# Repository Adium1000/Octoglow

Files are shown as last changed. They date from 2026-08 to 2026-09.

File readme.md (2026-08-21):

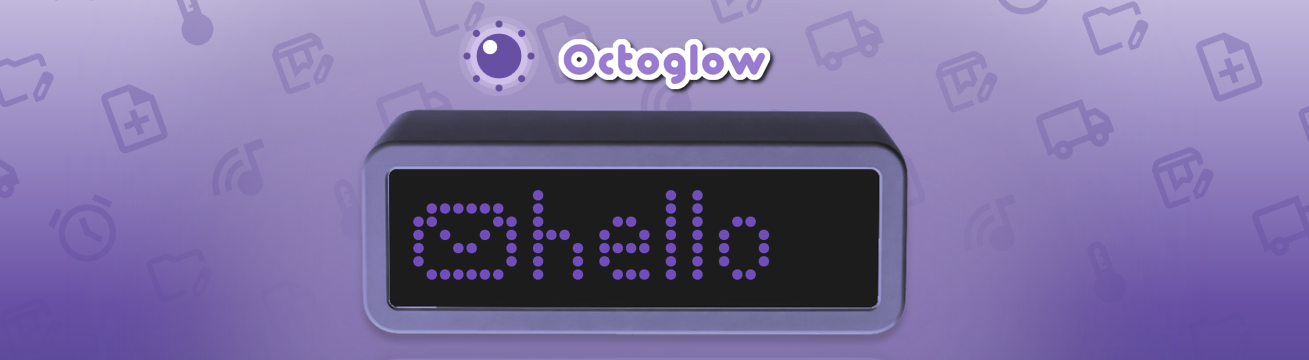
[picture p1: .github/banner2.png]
banner


A compact smart desk clock firmware that connects to Wi-Fi, syncs time automatically, and displays time, date, temperature, and atmospheric pressure  all in one firmware.

## Table of Contents

- [Features](#features)
- [DIY](#diy)
- [Bill of Materials (BOM)](#bill-of-materials-bom)
- [Octoglow Sender](#octoglow-sender)
- [Find my Octoglow's IP adress](#how-can-i-find-my-octoglows-ip-adress)

## Features
Octoglow displays information in "tiles" that rotate one after another, each with its own display duration, all configurable from the dashboard (you can enable/disable each tile and reorder them via drag & drop), Here is a list with all tiles:

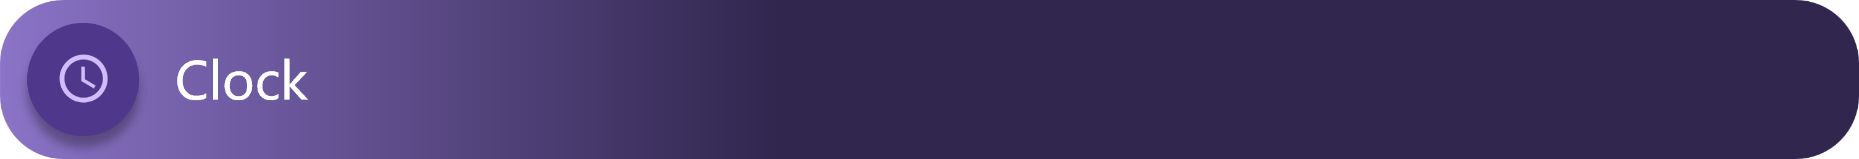
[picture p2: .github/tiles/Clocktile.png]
#clock


This tile shows the current time, synced automatically once the clock connects to the internet, so you never have to set it by hand.

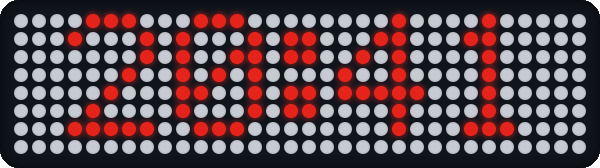
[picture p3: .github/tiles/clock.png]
Clocktile


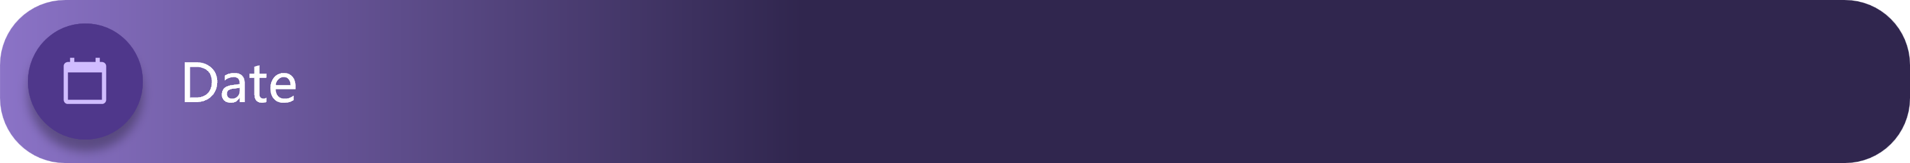
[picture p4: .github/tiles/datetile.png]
datatile


This tile shows the current date, pulled from the same internet time sync as the clock, so it always stays accurate.

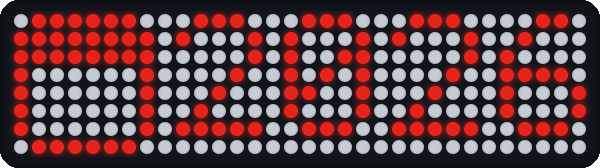
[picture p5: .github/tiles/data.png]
Datatile


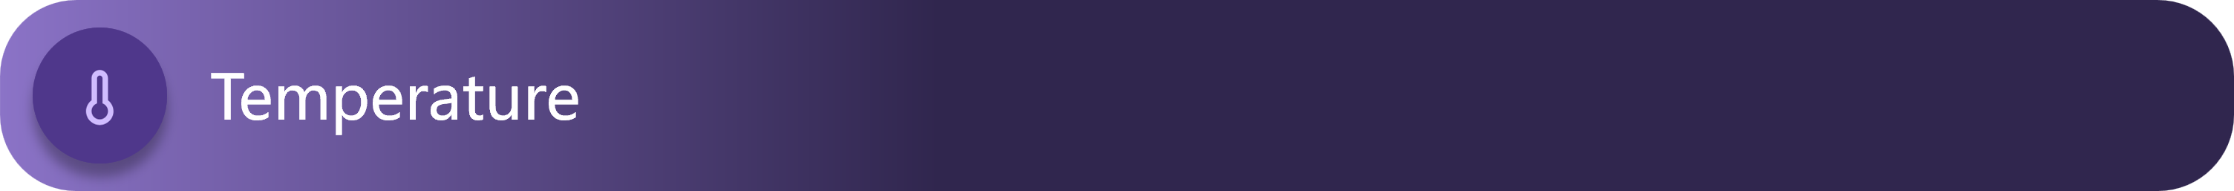
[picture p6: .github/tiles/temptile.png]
temptile


This tile shows the ambient temperature at your clock's location, as long as you have a temperature sensor connected to the i2c rails.

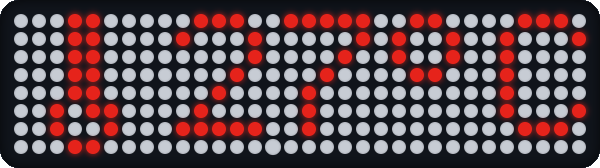
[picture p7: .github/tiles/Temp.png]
Temptile


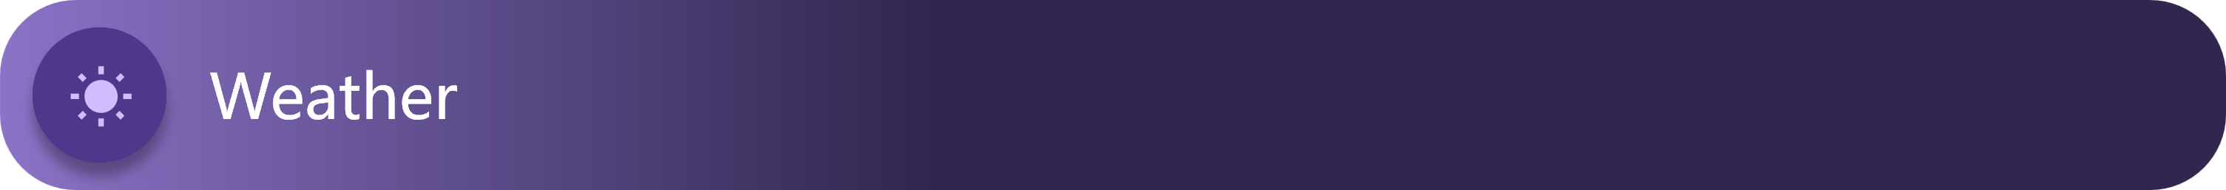
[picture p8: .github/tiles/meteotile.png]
meteotile


This tile fetches live weather data for your set location once you add an OpenWeatherMap API key. It scrolls through the current temperature (in Celsius or Fahrenheit, your choice), humidity percentage, and a short text description of the conditions, along with a matching weather icon.

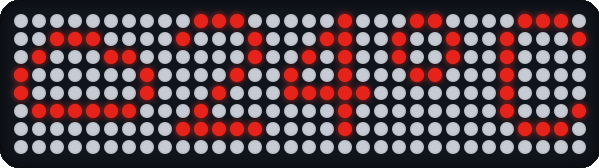
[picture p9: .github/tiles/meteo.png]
WeatherTile


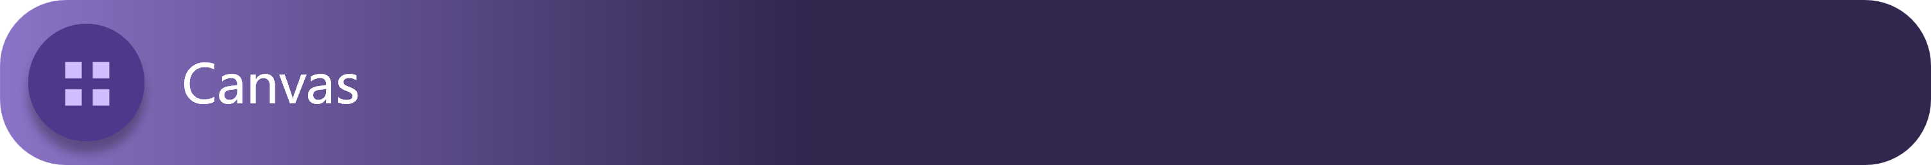
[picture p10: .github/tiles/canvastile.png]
canvastile


This tile turns the whole 8x32 LED matrix into a drawing surface, letting you sketch or design your own custom pixel art directly on the display.

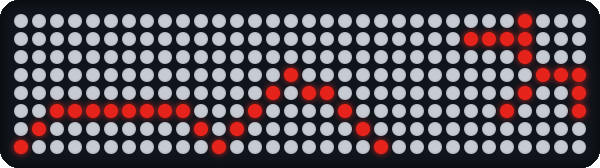
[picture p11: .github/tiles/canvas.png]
CanvasTile


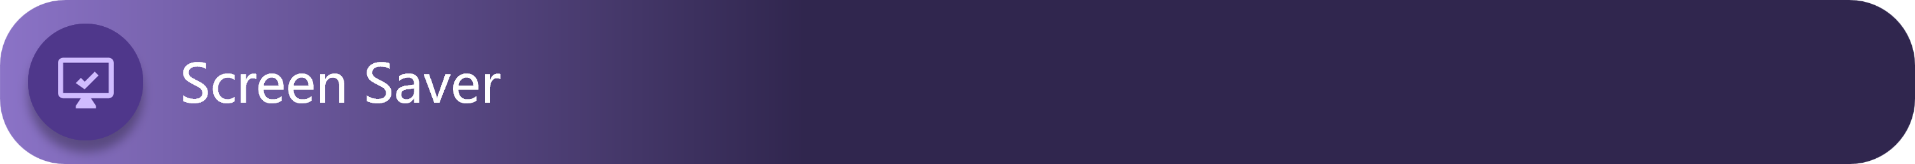
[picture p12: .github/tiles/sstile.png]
sstile


This tile plays one of three animations when idle: a self-playing Pong match between two paddles, a fireworks show with launching rockets and bursting particles, or an audio equalizer style animation with bouncing bars. You can pick a specific one or let it choose randomly each time.

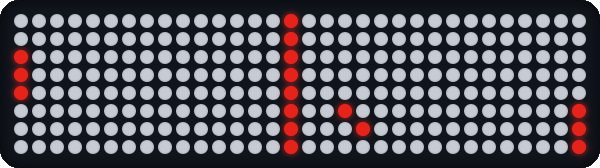
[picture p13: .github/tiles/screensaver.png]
screenssavertile


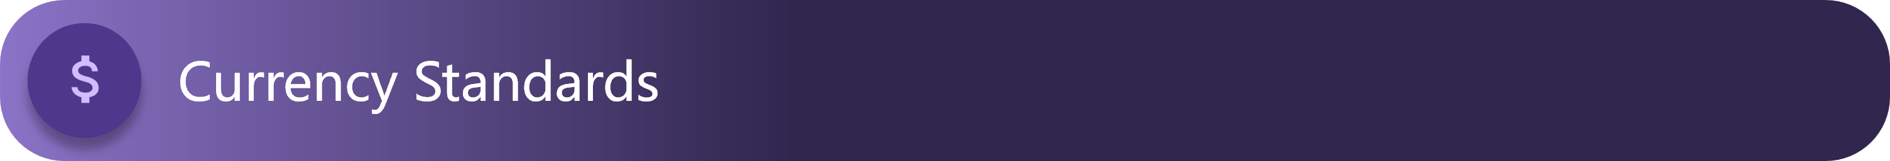
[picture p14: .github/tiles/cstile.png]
cstile


This tile shows the exchange rate for a currency you select, and optionally compares it against a second currency. It also displays a trend arrow showing whether the rate has gone up, down, or stayed flat compared to a month ago.

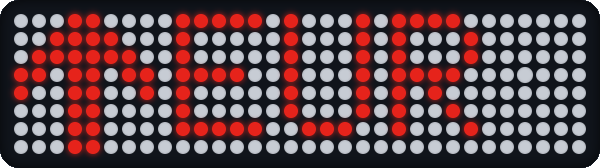
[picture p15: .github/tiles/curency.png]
curencytile


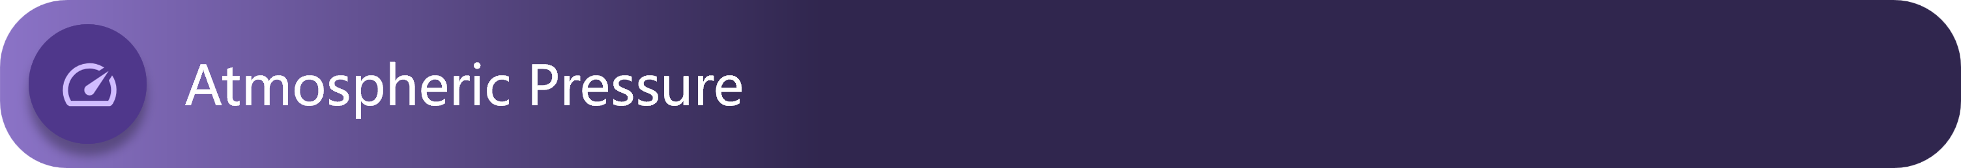
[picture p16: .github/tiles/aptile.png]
aptile


This tile shows the current atmospheric pressure in hPa, as long as your clock has a barometric pressure sensor connected to the i2c rails. It also shows a trend arrow based on how the pressure has changed over recent readings.

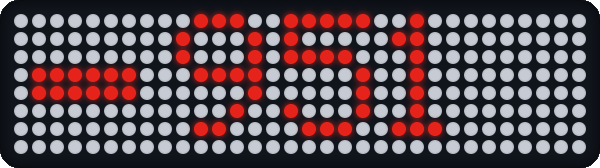
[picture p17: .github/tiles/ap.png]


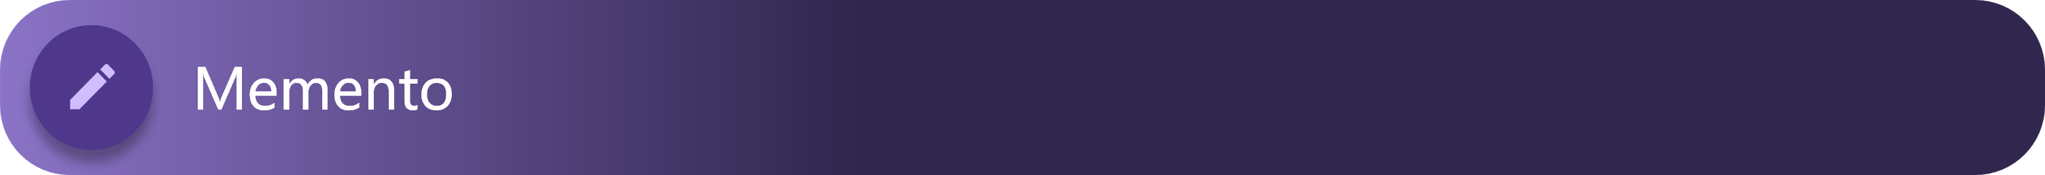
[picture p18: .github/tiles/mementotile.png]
Memento


This tile lets you create short personal notes or reminders that scroll across the display.

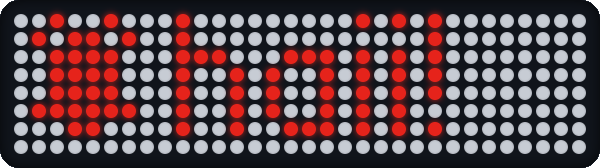
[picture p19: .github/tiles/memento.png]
Memento?Nahbro


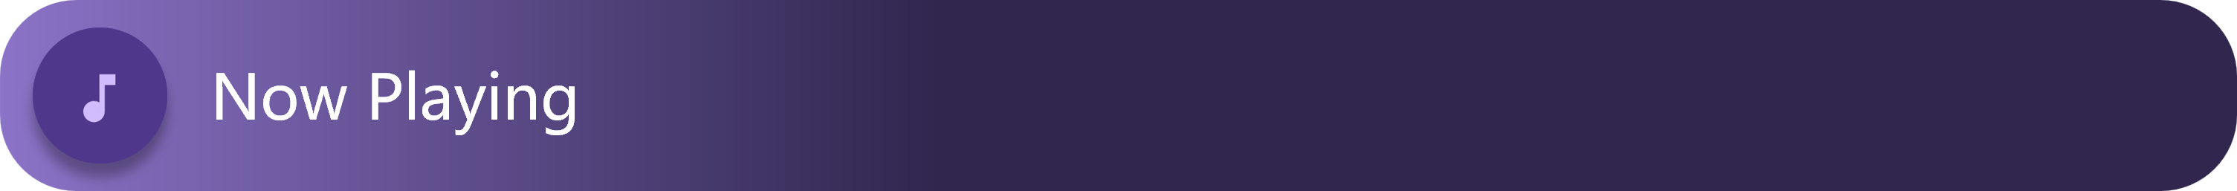
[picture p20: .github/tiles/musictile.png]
musictile


This tile displays the artist and track title of whatever you're currently listening to on your device, sent live from the companion Watch Sender app.

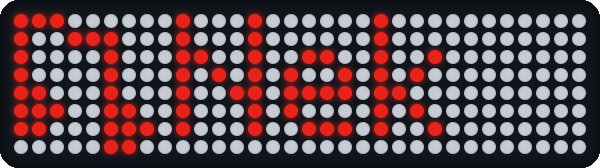
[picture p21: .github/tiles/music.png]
HmmNowPlayingGuta?


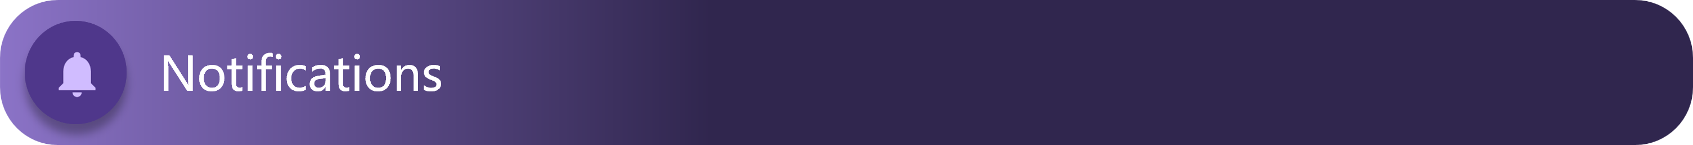
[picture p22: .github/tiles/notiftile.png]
notiftile


This tile shows notifications received on your computer as they come in, forwarded through the Watch Sender app and scrolled across the display.

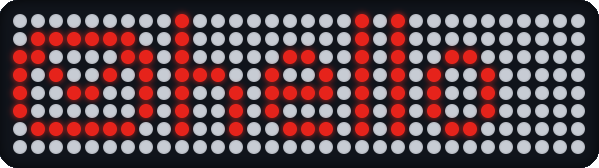
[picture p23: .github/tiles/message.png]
Ugotmailtile


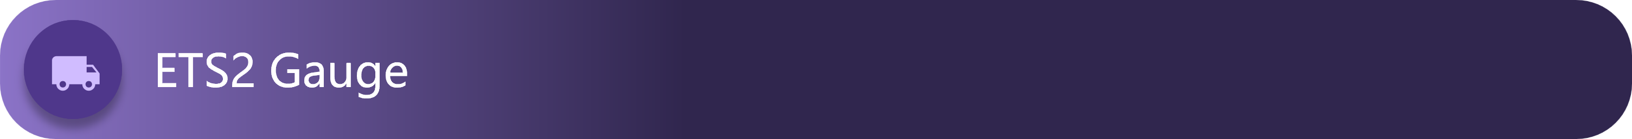
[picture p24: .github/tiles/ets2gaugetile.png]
ets2


This tile shows your real-time speed in km/h while driving in Euro Truck Simulator 2, streamed live from the game through the Watch Sender app.

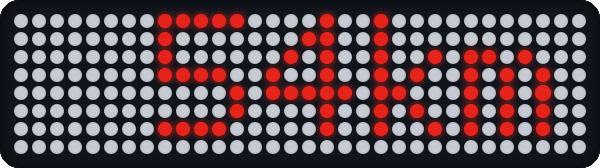
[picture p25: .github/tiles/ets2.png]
Ets2tile


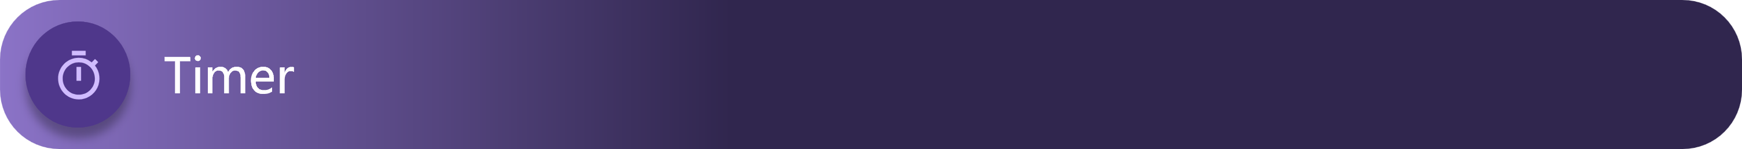
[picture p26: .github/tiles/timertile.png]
timertile


This tile runs a countdown timer that you can set to a custom duration or pick from preset values, showing the remaining time and alerting you with a sound once it hits zero.

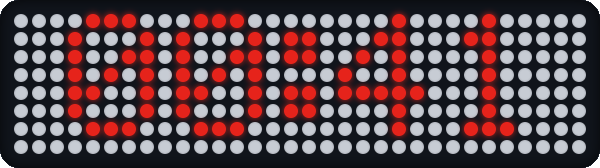
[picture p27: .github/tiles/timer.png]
tikitikitikitile


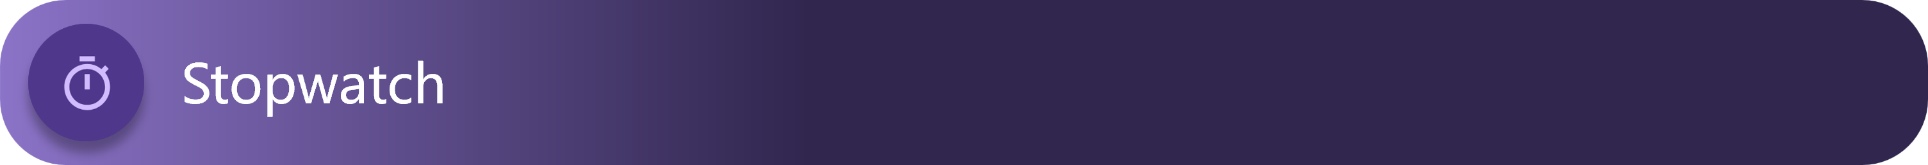
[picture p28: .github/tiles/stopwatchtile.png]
stopwatchtile


This tile lets you time things using your clock, with start, pause, and reset controls right from the interface.

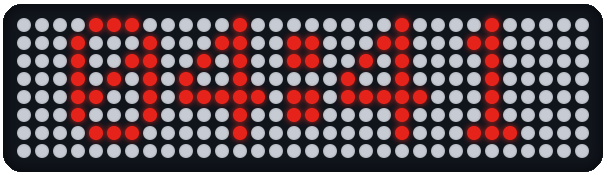
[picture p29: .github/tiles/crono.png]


## Configurations and Settings

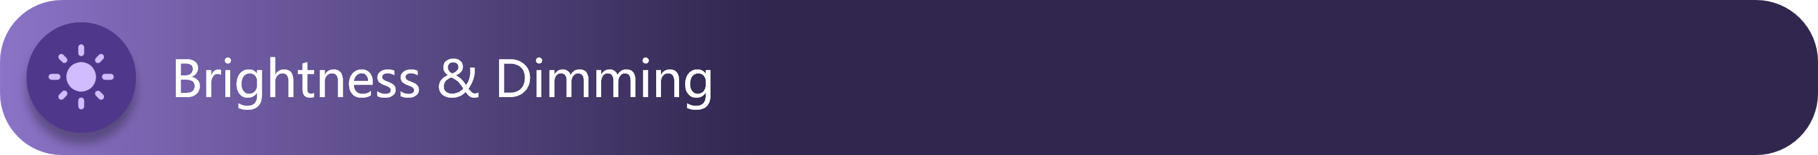
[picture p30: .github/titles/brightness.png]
Brightness & Dimming


- 17 brightness levels (0 = display fully off, 1-16 = actual intensity on the MAX7219 matrix).
- **Scheduled auto-dimming**: set a time window (e.g. 10 PM - 7 AM) during which the display automatically switches to a lower brightness, so it doesn't blind you at night.

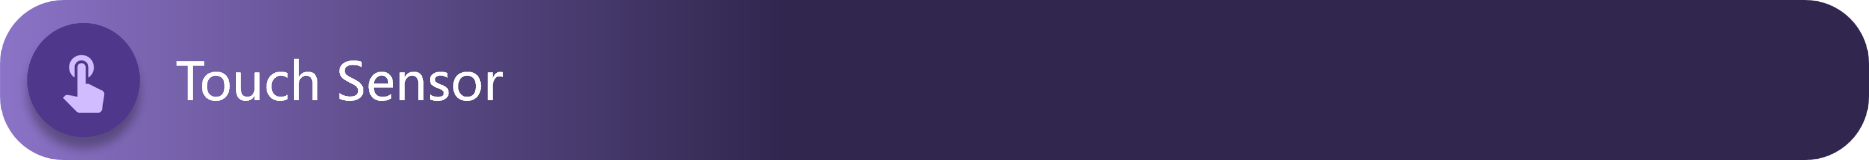
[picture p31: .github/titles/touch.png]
Touch Sensor


A TTP223 capacitive sensor enables physical interaction with the clock, with separately configurable actions for **tap** and **double tap**:

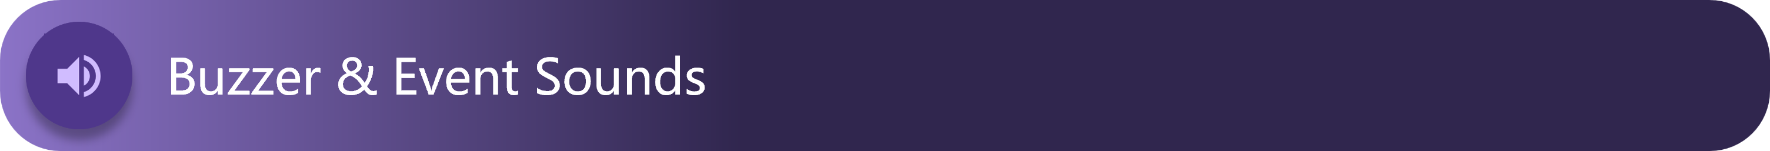
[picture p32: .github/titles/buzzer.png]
Buzzer & Event Sounds


- Buzzer on/off 
- Sound presets: Calm, Loud, Urgent, Soft, Double Beep, Triple Beep.
- Separately configurable sounds for each event type: tile switching, Wi-Fi disconnection, new notification, ETS2 speeding, touch sensor tap  with a wider tone library available here too (Chime, Bell, Doorbell, Xylophone, Harp, Marimba, etc.).

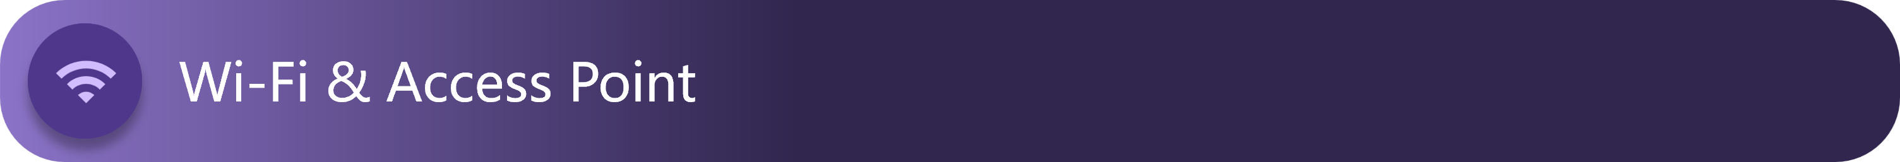
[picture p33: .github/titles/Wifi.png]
Wi-Fi & Access Point


- Connects to your Wi-Fi network (STA mode) via in-browser provisioning: network scan, password entry.
- If no Wi-Fi is configured (or if you choose to switch manually), it starts its own **AP hotspot** (defaults to "Octoglow"), with a configurable SSID and password, for direct access to the dashboard.
- You can switch between AP mode and Wi-Fi mode from the dashboard at any time.

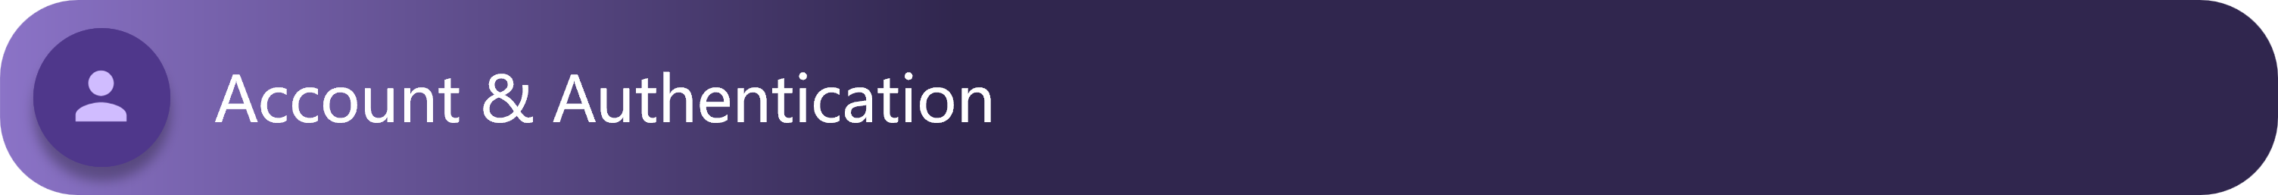
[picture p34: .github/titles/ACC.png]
Account & Authentication


The dashboard is protected with a username + password (cookie-based session). You can change your username and password anytime from the account section.

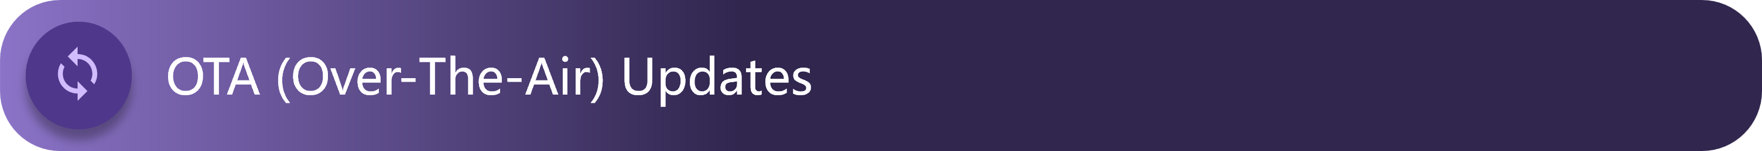
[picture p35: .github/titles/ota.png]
OTA (Over-The-Air) Updates


The firmware can check its own version against the GitHub repo and update itself wirelessly, straight from the dashboard:

1. The clock reads the published version from the repo and compares it against the installed version (`FW_VERSION`).
2. If a newer version is available, the dashboard shows the changelog and an install button.
3. The update (`.bin`) is downloaded and flashed onto the ESP32 via the `Update` library, followed by an automatic restart.

## DIY

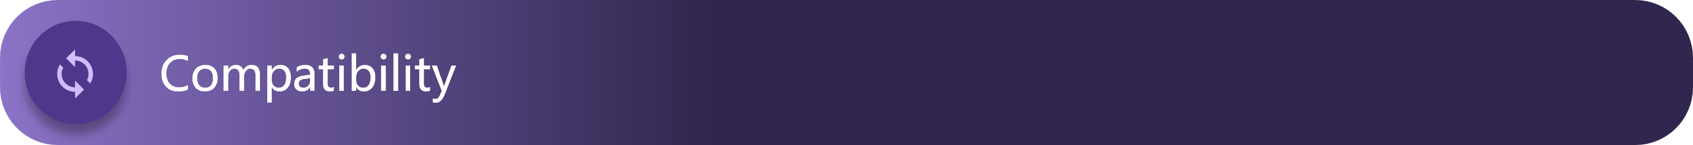
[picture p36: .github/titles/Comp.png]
Compatibility


The firmware should work on any ESP board, although it was tested on the following boards:

- ESP32-S3
- ESP32-C3

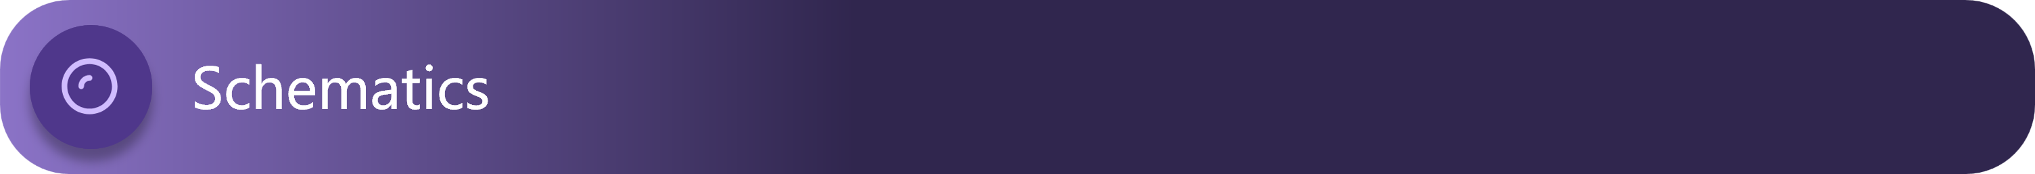
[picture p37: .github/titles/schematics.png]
Schematics


Here is a full schematic you can build if you want your Octoglow to run on battery
(the battery circuit is optional and can be skipped).

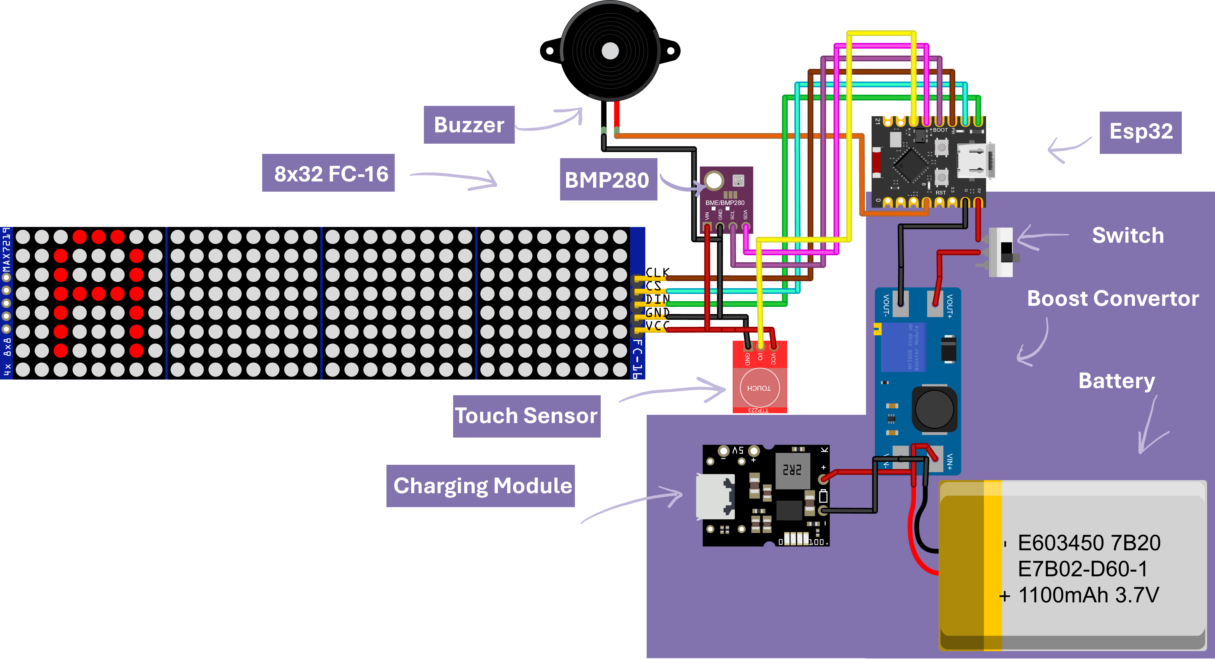
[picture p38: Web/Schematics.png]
schematics


| Component | GPIO |
|---|---|
| MAX7219 DIN | GPIO1 |
| MAX7219 CLK | GPIO3 |
| MAX7219 CS | GPIO2 |
| BMP280 SDA | GPIO5 |
| BMP280 SCL | GPIO4 ||
| Touch I/O | GPIO6 |
|Buzzer| GPIO7|
---

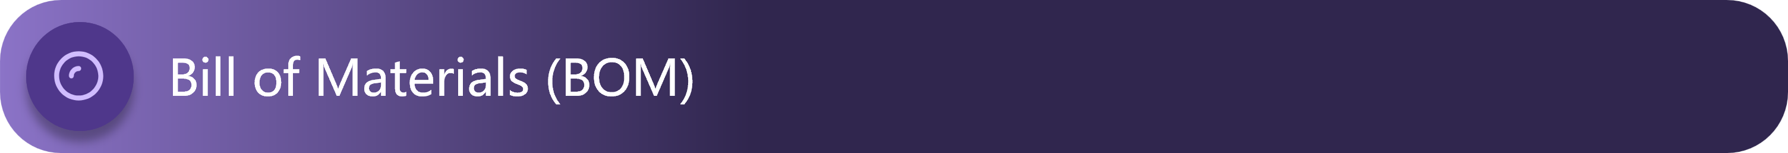
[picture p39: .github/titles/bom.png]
Bill of Materials (BOM)


| Item | Description | Qty | Unit Price ($) | Total ($) | URL |
|---|---|:---:|---:|---:|-----|
| LED Matrix 4x MAX7219 | 4-in-1 chained MAX7219 red LED matrix module | 1 | $6.98 | $6.98 | [Link](https://sigmanortec.ro/en/led-matrix-module-4x-max7219-red) |
| ESP32-C3 SuperMini | WiFi/BT microcontroller board 3.3V | 1 | $6.09 | $6.09 | [Link](https://sigmanortec.ro/en/esp32-c3-supermini-development-board-33v-wifi-bluetooth) |
| TTP223 Touch Sensor | Capacitive touch button module | 1 | $0.69 | $0.69 | [Link](https://sigmanortec.ro/en/capacitive-button-ttp223-touch) |
| TP4056 + Boost 5-24V | Battery charger with boost converter 5-24V | 1 | $1.75 | $1.75 | [Link](https://sigmanortec.ro/modul-incarcare-baterie-cu-ridicator-5-24v-tp4056) |
| IP2312 Charger USB-C 3A | Li-Ion charger 5V→4.2V CC/CV Type-C 3A QC | 1 | $2.75 | $2.75 | [Link](https://sigmanortec.ro/modul-incarcare-litiu-5v-la-42v-ip2312-cv-cc-type-c-3a-qc) |
| Mini Switch | Small slide switch, 2 positions | 1 | $0.22 | $0.22 | [Link](https://sigmanortec.ro/en/mini-switch-2-positions) |
| 18650 2500mAh x2 | Samsung 25R 18650 3.7V 2500mAh - set of 2 | 1 | $15.55 | $15.55 | [Link](https://sigmanortec.ro/set-2-acumulator-li-ion-25r-18650-37v-2500mah-8c) |
| BMP280 Sensor 5V | Pressure and temperature sensor 5V | 1 | $2.03 | $2.03 | [Link](https://sigmanortec.ro/en/pressure-and-temperature-sensor-bmp280-5v) |
| 3D Printing | Custom 3D printed case (Printing Legion) | 1 | $12.00 | $12.00 | - |
| **TOTAL** | | | | **$48.06** | |

---

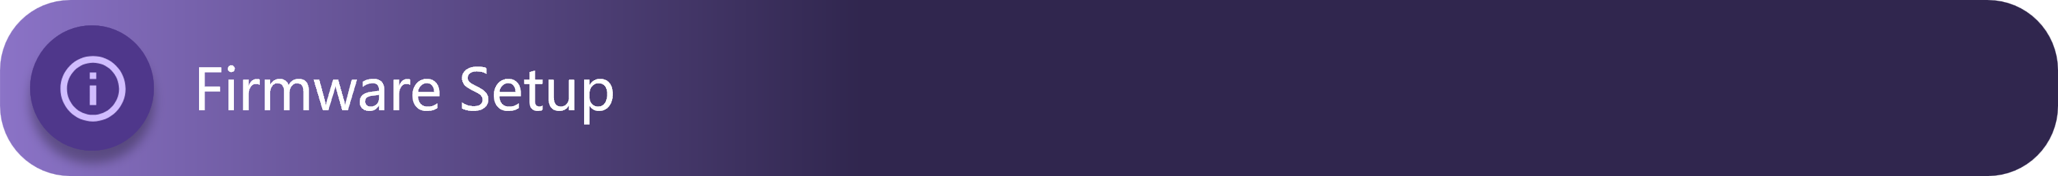
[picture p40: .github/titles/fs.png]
Firmware Setup


1. Open `Octoglow.ino` in the Arduino IDE (You can get it form `/Firmware/`)
2. Install the ESP32 board package from Boards Manager, if you don't have it yet.
3. Install the required libraries from the Library Manager:
   - `MD_Parola`
   - `MD_MAX72xx`
   - `Adafruit_BMP280`
   - `ArduinoJson`
   - (`WiFi`, `SPI`, `Wire`, `WebServer`, `Preferences`, `HTTPClient`, `Update`, `StreamString`, and `mbedtls` are already bundled with the ESP32 core)
4. Select your board and the correct serial port.
5. Upload the firmware.
6. On first boot, the clock starts in **AP mode**  connect to its Wi-Fi network and open `192.168.4.1` in your browser to set up its connection to your home network.

## Octoglow Connect

Octoglow Connect is a app that makes your matchine comunicate with your octoglow device by sending data over the internet to your octoglow device

Octoglow_Connect

What it does?

- **Now Playing**  detects the song currently playing on your Matchine (Spotify, browser, etc.) via the Windows Media Session and sends it every few seconds.
- **Windows Notifications**  listens for toast notifications on Windows and forwards them to the clock (with automatic diacritics removal and truncation to a maximum character count).
- **Euro Truck Simulator 2**  if the game is running, reads live telemetry (current speed) and streams it to the clock in real time. Requires an extra one-time plugin install in-game  see Setting Up ETS2 Speed Integration.

Setting Up

First, you will need to get you Octoglow's IP adress and insert it in the `IP Adress` text box (you can ignore the port most of the times) in the conection tab

### How can I find my Octoglow's IP adress?

## By router's dashboard

- You can find your Octoglow's IP adress in your router's dashboard 
 - Go to `192.168.0.1` or `192.168.1.1` depending on your router 
   - Login to your router's dashboard (the credentials are ushually writen on the back of your router or you can try User : user and Password:admin )
      - Once logged in look for a category named Clients or Devices or Conections or Whatever it really depends on your router
         - Once u find that category you should see a list of devices, each with an IP adress, and you should see a device named esp... that may be octoglow, copy the IPV4 adress and paste it in the adress bar, if you see the octoglow login screen , you are on the octoglow's dashboard

! Warning : Your octoglow IP adress may change after a while, your IP adress will change so you need to reserve IP address

## By tapping the touch sensor on your Octoglow 

- If you did not unasign the "show IP adress" in the touch sensor options it should show your IP , but your IP adress will change so you need to reserve IP address

Setting Up ETS2 Speed Integration

The ETS2 tile shows your truck's current speed on the clock, but it needs one extra piece set up in-game before it works: ETS2 doesn't expose any telemetry data on its own  a small plugin has to be installed first.

### Install the SCS SDK plugin (in-game)

1. Download the latest **scs-sdk-plugin** (by RenCloud) from:
   `https://github.com/RenCloud/scs-sdk-plugin/releases`
    grab the Windows archive (`win_x64`).
2. Open your ETS2 install folder. By default it's:
   ```
   C:\Program Files (x86)\Steam\steamapps\common\Euro Truck Simulator 2\bin\win_x64\plugins
   ```
   Create the `plugins` folder if it doesn't exist yet.
3. Copy the `.dll` from the downloaded archive into that `plugins` folder.
4. Launch ETS2. On first launch you may see a confirmation message that the SDK was enabled  click OK.

> If you don't see the confirmation message, make sure the DLL sits directly in `bin\win_x64\plugins\`, not in a subfolder.

## Photos of Octoglow in action

oct1
oct2

Made with 🖤 by Adrian

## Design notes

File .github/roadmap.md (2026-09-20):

# Devlog 1: Fixed the readme

Previously, my readme was written by ai, so it wasn't really that great. It contained a lot of false information about my project, so I decided to remake it, keeping only a few accurate parts from the previous version.
This update adds a lot of images and examples, as well as a banner, making the readme much more pleasant to look at. It took me quite a while to finish, but I'm really satisfied with the final result.

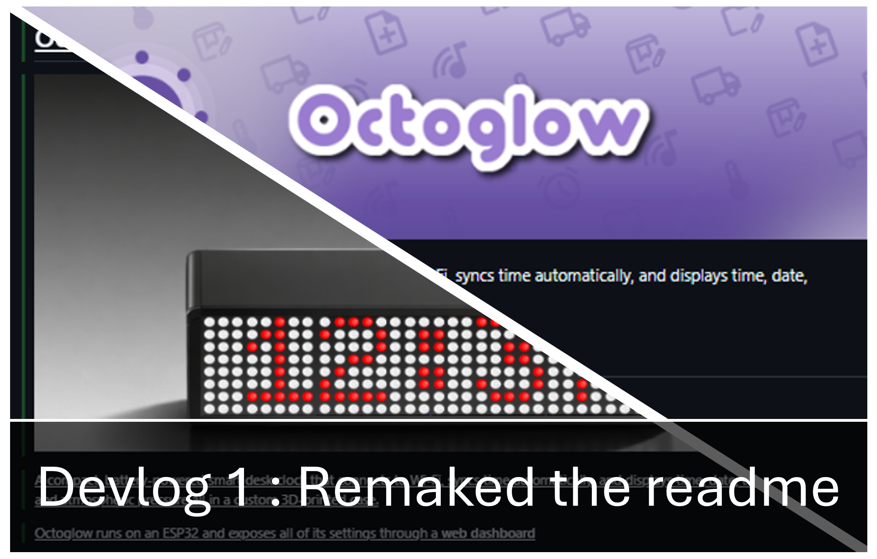
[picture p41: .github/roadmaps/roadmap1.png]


# Devlog 2: UI inconsistency error fixes + WiFi sync bug fix

1. UI inconsistency error fixes
- I tried to identify and fix all of them since in future versions we will be able to set the accent color for the interface
Below are all the fixes for the UI inconsistencies:
 - In Tile Manager: In the "Display Settings" category (My Project is still in Romanian and English, I will do a fix for that later) Tile Transition and Scroll Type used a different category opening arrow than the one on Disable Tile Icons, now they all look the same
 - In the "Switch to AP Mode" popup, the icon on the left and the confirmation button were red, which made the UI a bit inconsistent, now they follow the current accent color
 - In the About category, both Info and Software showed the version info, now it's only in Software, and the order was changed to Info, User, Software
 - In Display, in the "Brightness" category, the brightness icon had a smaller blade than the rest

2. Octoglow WiFi information sync errors

In the past, the firmware had a problem where if /state failed even once (a network blip on the ESP32), the page would permanently fall back to a reduced hardcoded list (without Pressure/Screensaver/Currency) and would stop updating IP/WiFi/version at all, which is why it only worked after a restart, since that redid the fetch
Fix applied: now, if /state fails, the page automatically retries up to 4 times (with increasing delay: 0.5s, 1s, 1.5s, 2s) before falling back to the incomplete fallback. This basically removes the need for a manual restart in unfavorable cases

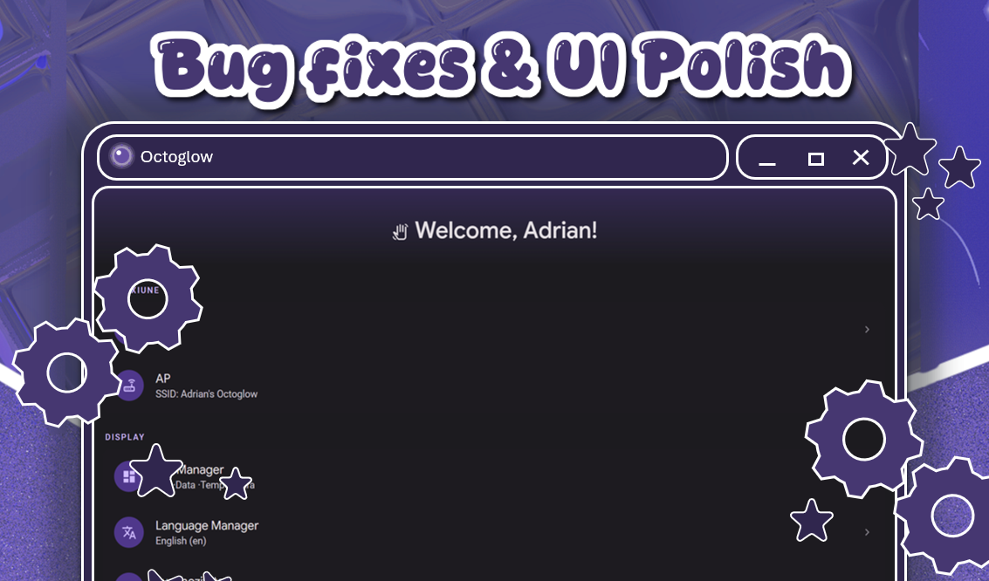
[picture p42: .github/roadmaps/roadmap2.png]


# Devlog 3: Text Engine Fixes

1. Tile Font Inconsistency
Before this fix, the timer, stopwatch, memento, and currency tiles used a different numeric font than the rest of the tiles, something I hadn't noticed until now. As of this update, all tiles now display using the same font.

Before

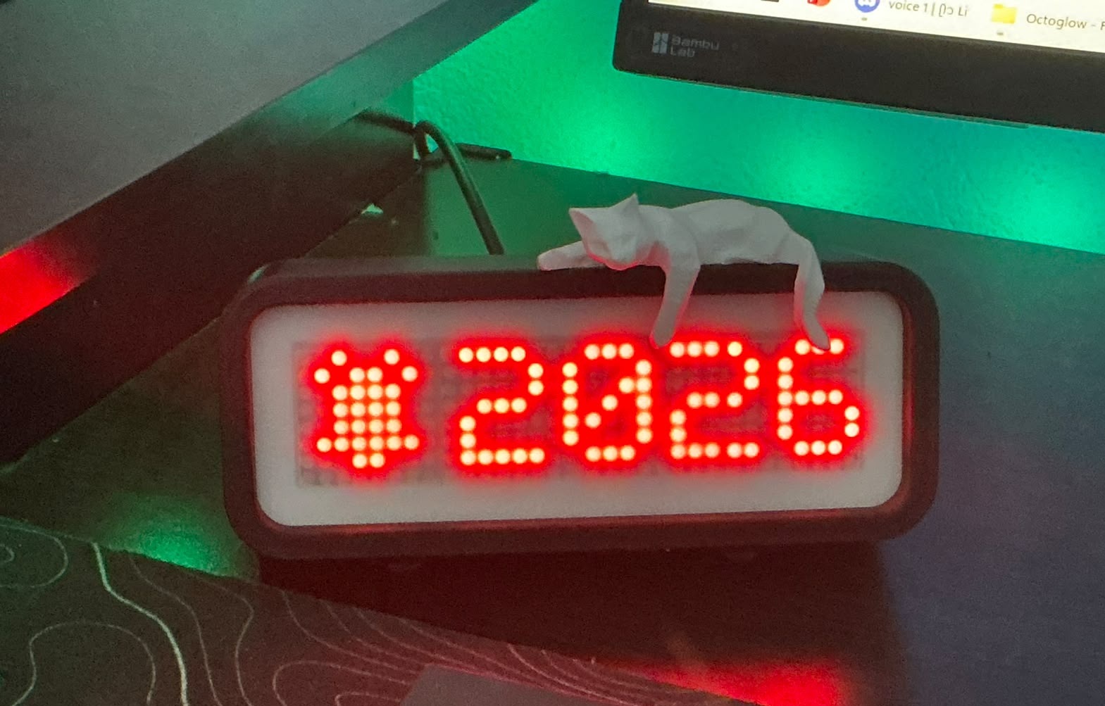
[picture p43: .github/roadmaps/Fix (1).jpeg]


After

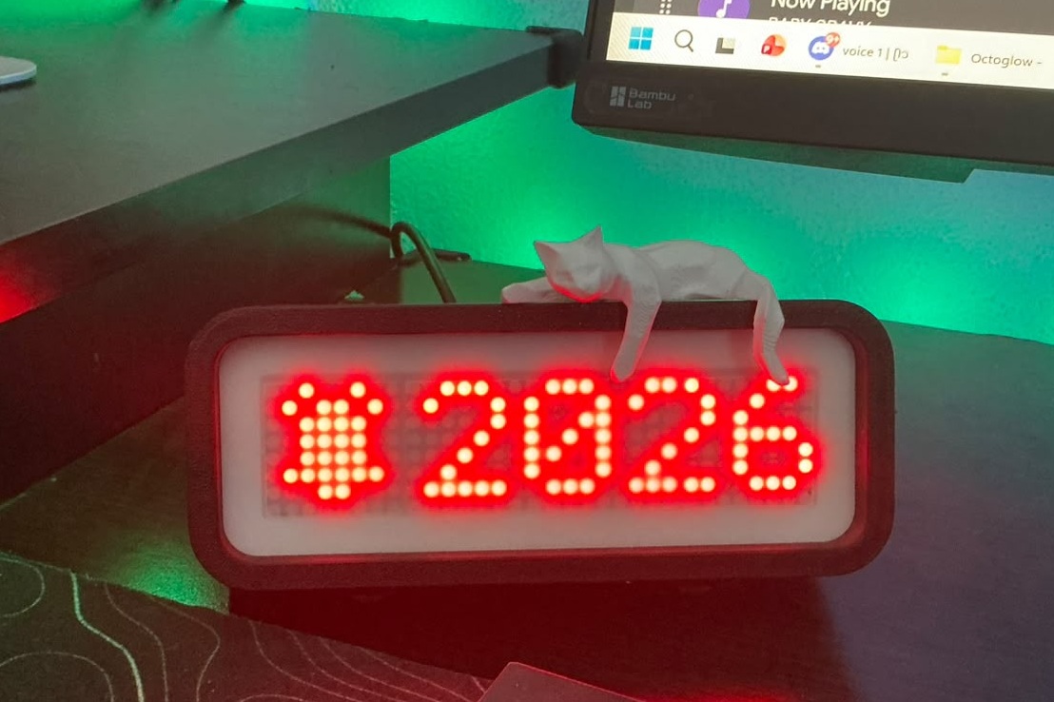
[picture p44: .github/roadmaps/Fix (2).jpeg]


2. Toasts
In previous versions, when logging into the interface, we had no dedicated way to communicate short lived pieces of information, so these messages were scattered around and didn't look good. Starting with this update, the web interface now has the ability to display toasts (a feature I mainly integrated to warn the user that they cannot have 0 active circuit tiles, and that at least one tile of that kind needs to be turned on for the firmware to work correctly. However, I saw an opportunity in this, so I integrated it in other places as well).

Places where we now have toasts:
Failed Login
Successful Wifi Connection
Circuit Tile Exception
AP Mode Switch

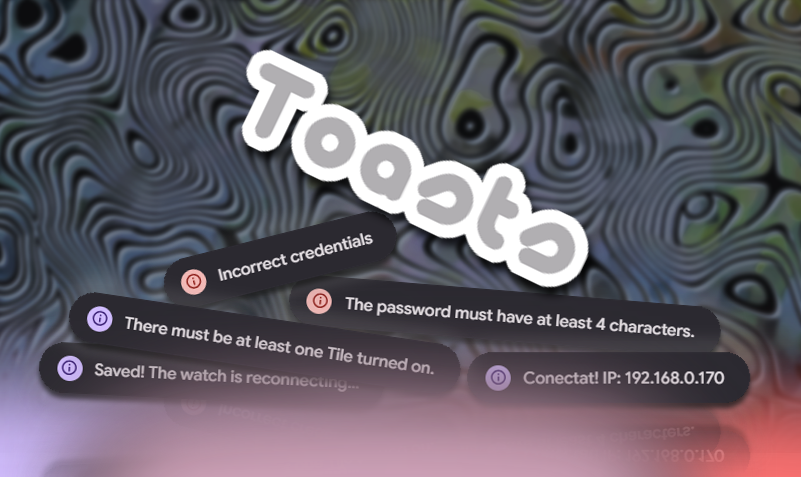
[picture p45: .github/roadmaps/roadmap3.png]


# 4. Fixed tile engine + Easy Discover Utility
### Animation transition fix

Fixed the animation transition on single circuit tiles for a smoother and more consistent visual experience.

### Show IP address through Touch actions

You can now assign `Show IP Address` to `On Touch` or any other supported Touch event from the Touch Options menu.

When triggered, Octoglow will display its current IP address directly on the device. This can be especially useful when using a hotspot for synchronization, or when you want to connect to Octoglow without having to dig through your router settings to find its address.

It makes accessing the interface and setting up synchronization a little easier and more convenient.

## README Updates

### Photos of Octoglow in Action

A new section has been added to the README: **Photos of Octoglow in Action**.

This section is intended as a community gallery where you can share photos of your own Octoglow device. The goal is to build a diverse collection of setups that shows the different ways Octoglow can be used, customized, and built into your own projects.

Whether you went for a clean setup, something completely custom, or found a use case we never thought of, feel free to share it.

And yes, ideally with Octoglow actually being the star of the show. Although I have a feeling some of you might have other plans.

# 5. UAC Redesign + NowPlaying Number Font Fix

## Redesigned the old UAC
Gave the old UAC (login/setup screen) a visual refresh to make it feel more modern and pleasant to use. The layout is now more minimal overall, with less clutter and less text on screen. One of the nicer additions is an automatic guest avatar that generates your initials from the username you type, instead of showing a generic placeholder icon the whole time. Spacing and alignment were also cleaned up so the screen looks tidier on both small and large displays.

## Fixed NowPlaying numeric font
Noticed that the NowPlaying tile was rendering its numbers with a different font than every other tile in the UI, which made it stand out in a bad way. Tracked it down and fixed it so NowPlaying now uses the same numeric font as the rest of the tiles, keeping everything visually consistent.

# 6. Accent Color + 15 New Buzzer tones 

# Accent Color

Now you can change the accent color of the dashboard from the default pink up to any color, (except white and black because they are not colors and they will broke the dashboard) Also there are some prests that I find them looking cool and also an option to custum hex , and restore

And added light mode, if you'd like to use your monitor as a flashlight

# Buzzer Tones

Added a few new buzzer tones, they are pretty basic
Here Is the full list of buzzer tones 

- Calm
- Loud
- Urgent
- Soft
- Double Beep
- Triple Beep
- Chime
- Bell
- Doorbell
- Xylophone
- Harp Glissando
- Marimba
- Crystal Sparkle
- Gentle Wave
- Lullaby
- Ping Pong
- SOS
- Siren
- Klaxon
- Klaxon
- Laser Zap
- Robot Blips
- Fanfare 
- Power Down
- Power Up
- Heartbeat
- Sci-Fi
- Arcade
- Zen Gong
- Bubbles
- Whistle
- Bold Alert

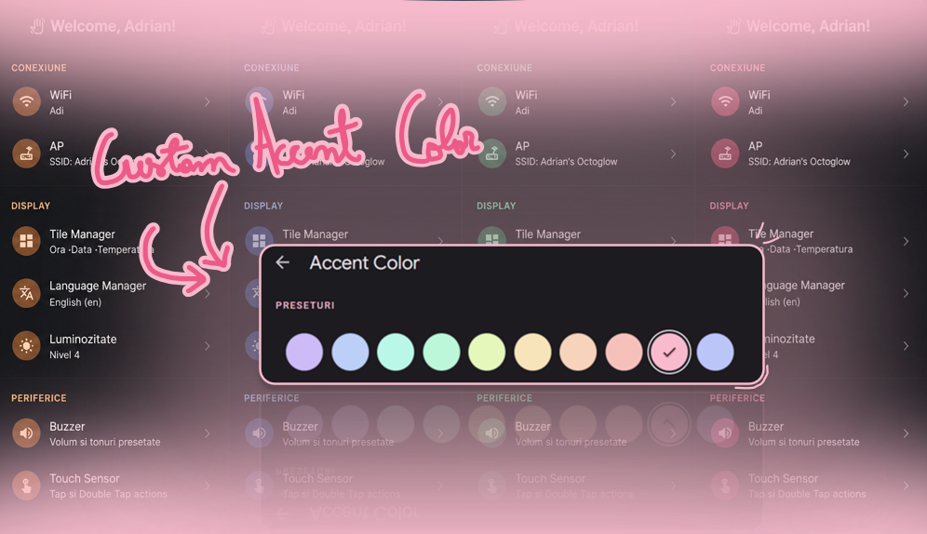
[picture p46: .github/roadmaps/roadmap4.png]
dd


# 7. Released the Octoglow Website + Major Firmware Fixes

## 1. Octoglow Website

Released the new **Octoglow Website**! This page makes the Octoglow setup and introduction easier for new users, while also providing a way to try out the Octoglow dashboard.

## 2. Firmware Updates

* **Fixed Tile Font Issues:** Fixed numeric font issues affecting the following tiles:

  * IP Address
  * Notification

* **Fixed Text Scrolling Freezes:** Fixed most of the freeze issues that occurred when a tile was scrolling text.

* **"Looking for Something Else" Section:** Added a **"Looking for Something Else"** section to the Tile Manager and AP pages. This will help users find information related to these menus.

* **No Re-Login Required:** Fixed the login cache issue. Now, even if you unplug your Octoglow, you can still access it without entering your password again, as long as you have previously logged in or revisited the page within the last 30 days.

* **Connection Issue Popup:** If your ESP loses its internet connection, a popup will now be displayed in the web interface to notify you.

* **Tile Manager Design Improvements:** Improved the design flow in the Tile Manager settings. All custom options for a tile are now displayed in a cleaner list format using radio buttons.

* **Help Manager:** Some tiles now have a **(?)** icon. Pressing it will show information about how to properly configure and use that tile.

* **Custom Date Formatting:** You can now customize the date format however you want using:
  **W, Y, M, D, /, , and .**

Connector App + App Patch

1. Released Octoglow Connect -  A remade version of Octoglow Sender but in C# 

- This app should be more stable, also this app provides more options like:
  - System Default Language Detector
  - System Default Theme Detector
  - Euro Truck Simulator truck Handbrake Detector
  - Now Playing Pause Detector
  - Now Playing Video Player Detecor (Avalabile in the last Python Version of Sender if you compile it by yourself)
  - Backdrop Material 

2. /state bugs fix

In the last patch of thre Octoglow Firmware, I tryed to patch the most reasons why the state command will fail to reach back the server, that may make the web experience smoother and more reliable 

3. Released Demo on the site 

Great news! If you want to test a Demo version of the web interface before flashing you can now try it

4. Fixed Schematics

Before the buzzer was connected on pin 7, now it is indeed conected in the pin 12
Maked the picture text more readable

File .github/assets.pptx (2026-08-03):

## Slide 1

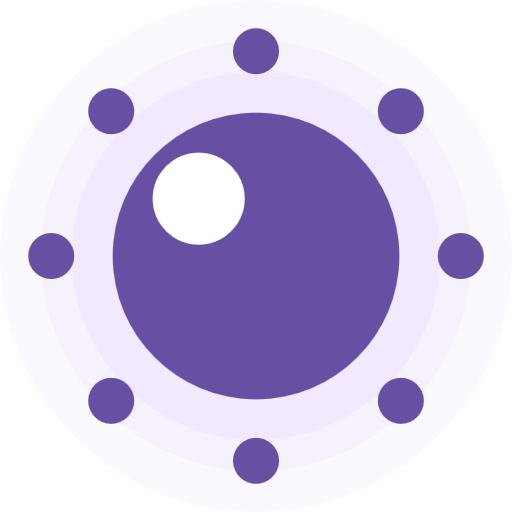
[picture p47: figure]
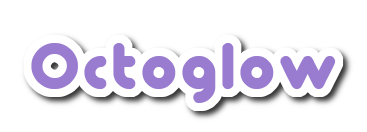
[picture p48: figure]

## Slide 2

Clock

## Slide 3

Clock

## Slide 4

Date

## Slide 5

Temperature

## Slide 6

Weather

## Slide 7

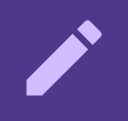
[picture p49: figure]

Memento

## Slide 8

Atmospheric Pressure

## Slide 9

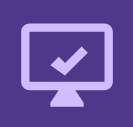
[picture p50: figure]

Screen Saver

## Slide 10

Currency Standards

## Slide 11

Notifications

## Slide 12

Timer

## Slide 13

Stopwatch

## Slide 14

Now Playing

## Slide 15

ETS2 Gauge

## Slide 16

Brightness & Dimming

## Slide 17

Wi-Fi & Access Point

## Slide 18

Account & Authentication

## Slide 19

Compatibility

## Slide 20

Bill of Materials (BOM)

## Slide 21

Bill of Materials (BOM)

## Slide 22

Setting Up ETS2 Speed Integration

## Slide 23

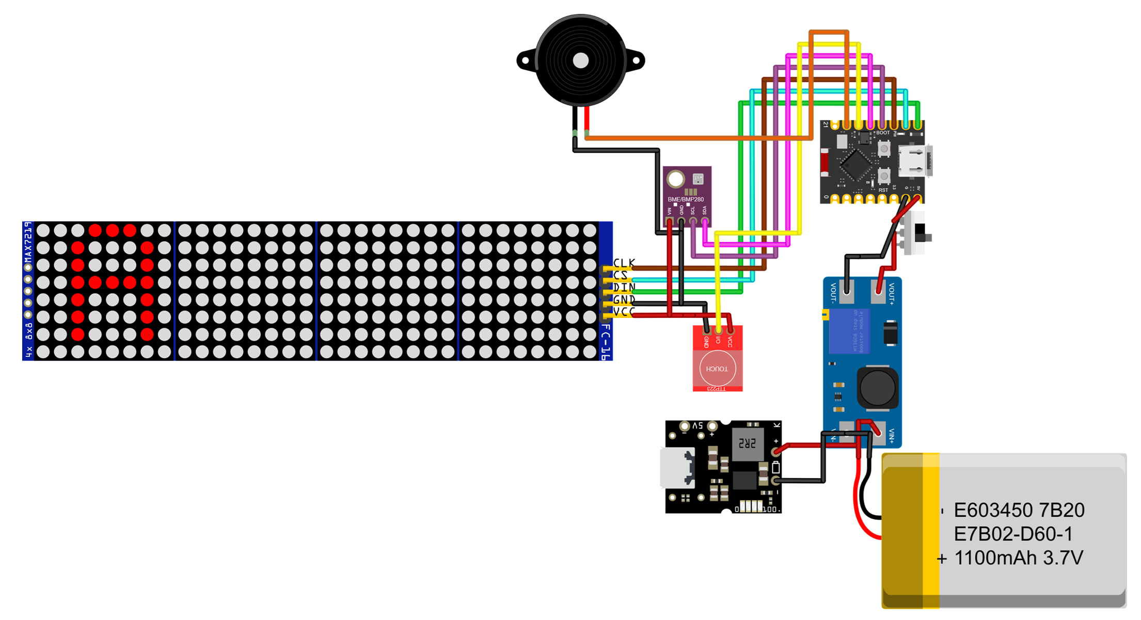
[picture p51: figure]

Buzzer

Esp32

8x32 FC-16

Boost Convertor

Switch

Battery

Touch Sensor

Charging Module

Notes: Charging Board

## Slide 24

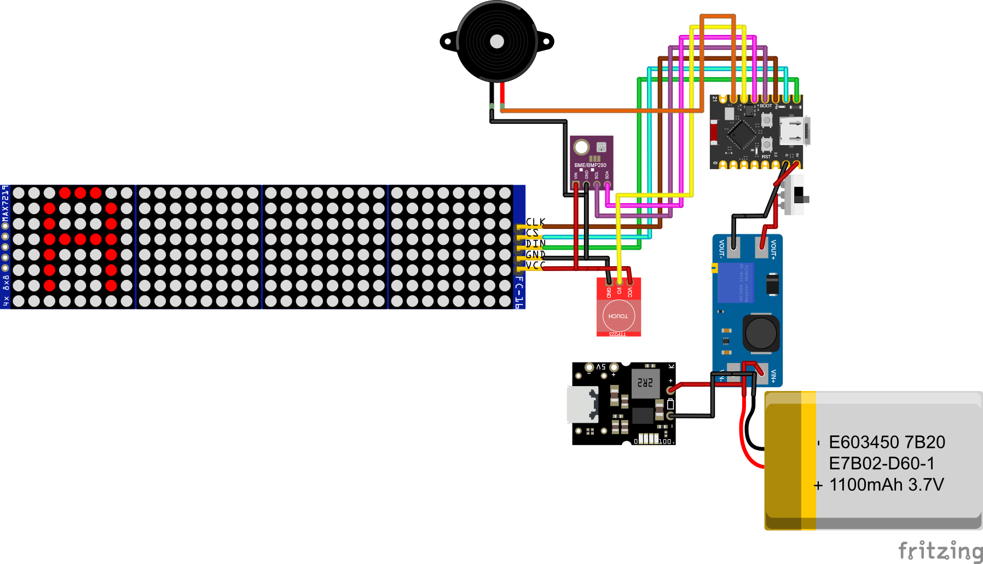
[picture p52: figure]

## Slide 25

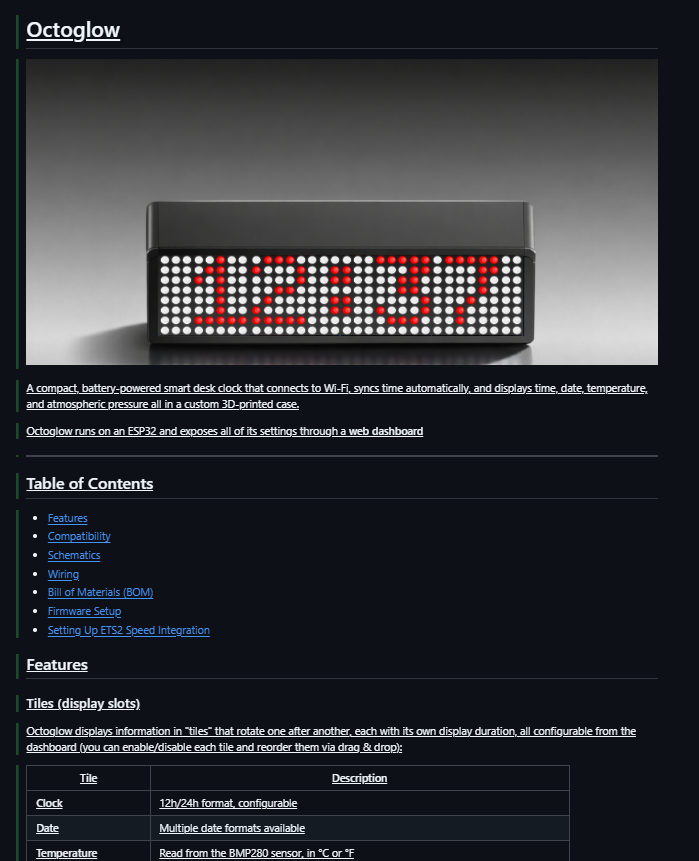
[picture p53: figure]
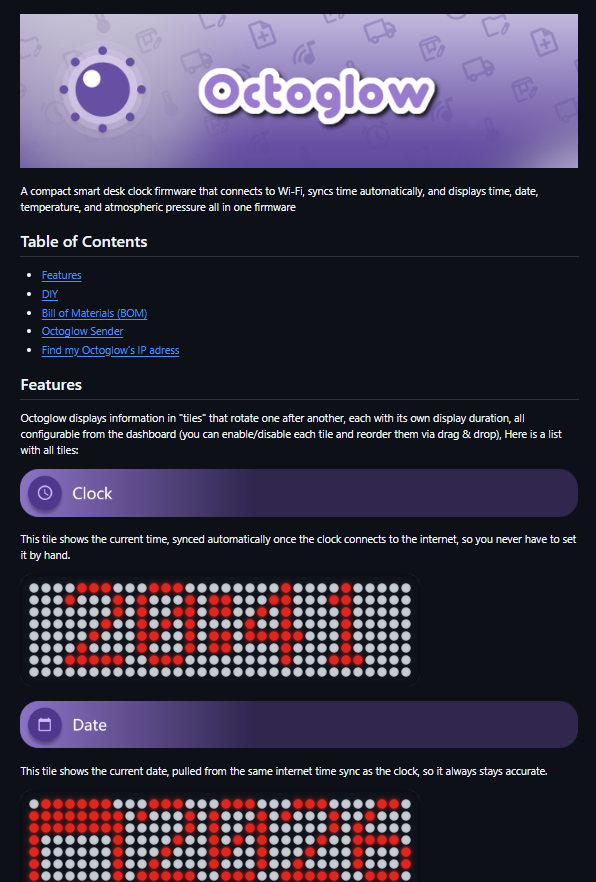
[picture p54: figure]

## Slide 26

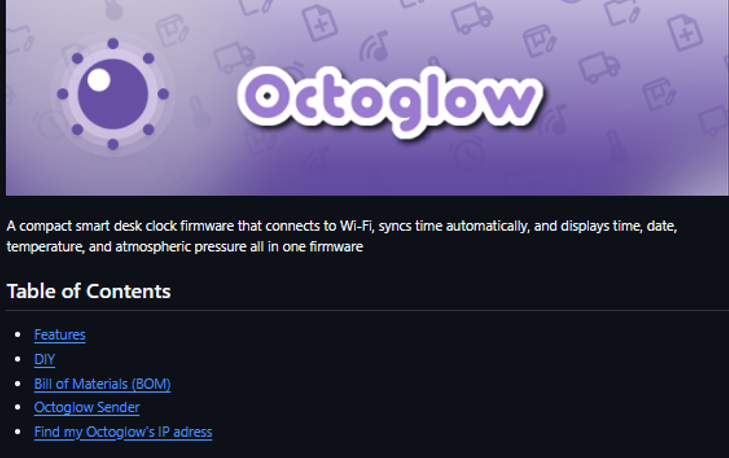
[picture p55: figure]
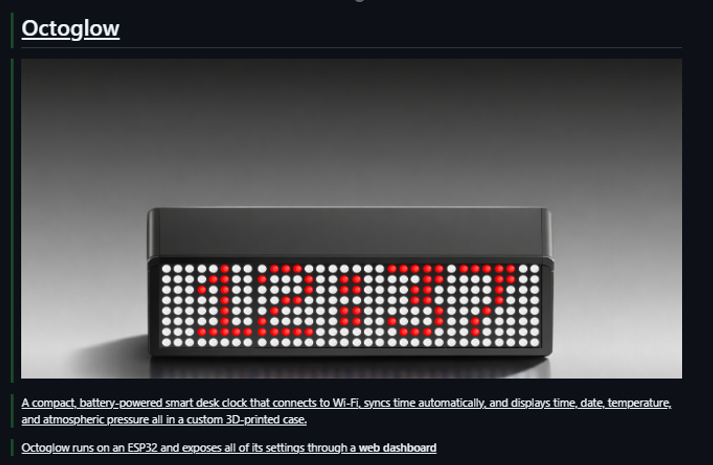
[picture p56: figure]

Devlog 1 : Remaked the readme

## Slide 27

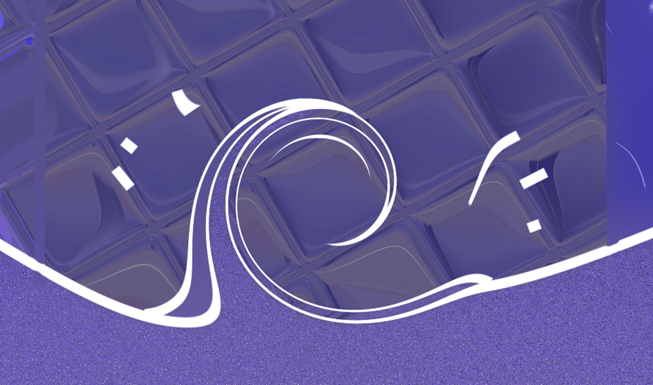
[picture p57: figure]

Octoglow

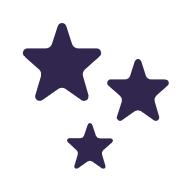
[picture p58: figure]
Stars with solid fill
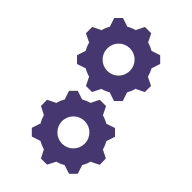
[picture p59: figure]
Gears with solid fill
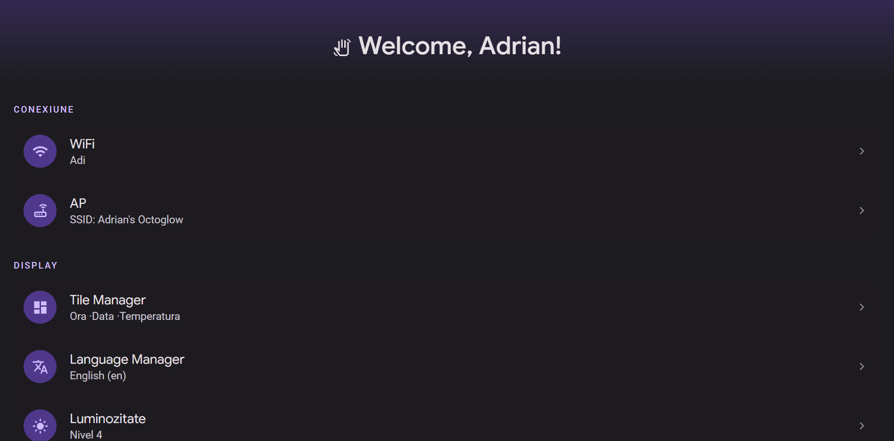
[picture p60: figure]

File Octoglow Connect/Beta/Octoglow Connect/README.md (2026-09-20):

# Octoglow Connect 2.0

Octoglow Connect este acum hub-ul comun pentru **Octoglow Desk Clock** și
**Octoglow Macro**.

## Ce este implementat

- listă dinamică de dispozitive în meniul din stânga;
- detectare automată Desk Clock în rețeaua locală prin endpoint-ul firmware
  `/authstate`, plus adresa salvată și adresa AP `192.168.4.1`;
- detectare hot-plug pentru Octoglow Macro prin USB HID;
- o pagină Desk Clock cu taburi separate pentru overview, integrări și activity
  log; setările Video/Music Now Playing și Euro Truck Simulator 2 sunt legate de
  acest dispozitiv;
- setările globale controlează doar aplicația: limba, tema, backdrop-ul, pornirea
  cu Windows și comportamentul din system tray;
- o pagină Macro cu VID/PID, revizie USB, layout fizic și highlight live pentru
  cele 7 taste și encoder;
- sender-ul Desk Clock rulează la nivel de aplicație și nu mai depinde de pagina
  deschisă;
- un singur router Win32 pentru tray și Raw Input, pentru a evita conflictele
  dintre hook-urile ferestrei.

## Limita actuală pentru Octoglow Macro

Mapările sunt afișate read-only. Firmware-ul trimite direct acțiunile HID și nu
există în proiect un protocol documentat de configurare (CDC sau HID output).
Aplicația nu deschide și nu hardcodează portul COM expus de placa TinyUSB.

Pentru remapping real, firmware-ul trebuie să trimită ID-ul fizic al tastei și
să ofere comenzi de tip `GET_CONFIG`, `SET_CONFIG` și `SAVE_CONFIG`.

## Build

```powershell
dotnet build .\OctoglowSender.csproj -c Release
```

Executabilul rezultat se numește `OctoglowConnect.exe`.

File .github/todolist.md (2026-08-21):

Welcome to my todo list

~~1. UAC fix, sa nu fie necesar sa ne logam de fiecare data cand moare ceasul~~ 

~~2 Fix icoana de luminozitate~~(2.8.26)

~~3. fix language piker on touch in sender~~ FUCIN NEW C# VERSION CUZE OF THAT

~~4. Fix number font~~ (3.8.26)

~~5. fix animation tranzion on single circuit tile on~~

~~6. fix non circuit tiles on~~ (3.8.26)

~~7. Ui cons fix~~ (2.8.26)

~~8. Page icon~~

~~9. Add ASCII art~~

~~10. Add to touch actions on touch show ip adress~~

~~11. Smart House integration~~ (Bullshit, after reading some docs it is not worth it)

~~12. Help Manager~~

 13. Limbă intrefata : Engleză Si Romana

 14. Reset & Restore & backup functions in about

 ~~15. Tile manager Custom Fonts~~

~~16. Custom accent color~~

~~17. Scrolling freeze bugs~~

~~18. AP scrolling Ip adress~~ Why did I added this?

19. AP settings one time show

20. AP set time witout  and date witout internet conexion

~~21. UAC redesign~~

~~22. Fix Now Playing number font~~

~~23. Looking for something else!~~

~~24. Login page redesign~~

~~25. Notification tile font issue~~

~~26. IP adress Scroling font issue~~

~~27. Data formatting DD/MM/YYY~~

~~28.Design Flow in tile manager settings~~

/State bugs

Nu, e important să fie clar: schimbarea asta e **pur cosmetică/UX**. Nu reduce numărul de erori reale și nu îmbunătățește stabilitatea backend-ului — doar ascunde de la utilizator faptul că datele nu sunt încă gata, în loc să-l lase să vadă un UI pe jumătate populat.

Concret, ce **nu** s-a schimbat:
- `/state` poate în continuare să eșueze (timeout, JSON incomplet, `hasCompleteCircuitState` fals) exact ca înainte — logica de retry (5 încercări, backoff 500ms/încercare) a rămas identică.
- Cauzele reale ale eșecurilor — buffer-ul ESP-ului care nu apucă să se umple, memorie insuficientă, `WiFi.scanNetworks` blocant, `Content-Length` greșit etc. — nu au fost atinse deloc.
- Dacă rețeaua e proastă sau device-ul e supraîncărcat, tot vei ajunge la eșecul final după 5 încercări — doar că acum utilizatorul vede un popup clar cu eroarea, în loc de tile-uri goale.

Ce **s-a îmbunătățit** cu adevărat:
- Percepția de stabilitate (nu mai vezi UI stricat/incomplet).
- Vizibilitate — acum vezi exact mesajul de eroare (`err.message`) în loc să ghicești de ce nu s-a încărcat ceva.

Dacă vrei stabilitate reală (mai puține eșecuri, nu doar ascunderea lor), ar trebui să mă uit la partea de server (`handleState`, cât de mare e payload-ul, dacă se face streaming corect, dacă `WiFi.scanNetworks` sau alte operații blocante rulează în timp ce se servește `/state`). Vrei să sap acolo?

Fragmentare heap din String, pe termen lung — ăsta e cel mai real risc. Ai ~110 utilizări de String (concatenări în handler-ele web, parsare JSON etc.). Pe ESP32, alocarea/dezalocarea repetată de String-uri de dimensiuni variabile fragmentează heap-ul încet, chiar dacă ai destulă RAM liberă în total. Simptom tipic: după zile/săptămâni de uptime continuu, apar crash-uri random sau Guru Meditation Error la un malloc care eșuează, deși teoretic mai ai memorie. Soluție pe termen lung: char[] cu buffere fixe în locurile fierbinți (build de JSON pt dashboard, request handlers).
Stutter la buzzer — melodiile tale folosesc tone() + delay() secvențial (ex: 5-6 note x ~50-100ms fiecare = până la jumătate de secundă blocat). În acel interval, loop-ul e complet blocat: matricea nu se actualizează, server.handleClient() nu se apelează, deci dashboard-ul poate părea "înghețat" scurt de fiecare dată când sună un sunet. Nu e grav (sub 1s), dar dacă cineva dă refresh pe dashboard exact când sună notificarea, poate vedea un request care durează puțin mai mult.
Riscul "un state uitat" — ai 31 de apeluri manuale la server.handleClient() distribuite prin cod, ca să ții dashboard-ul responsive în timpul animațiilor de scroll. Cu 16k linii și atâtea tile-uri/stări, e ușor ca la un tile nou adăugat în viitor să uiți acel apel undeva — nu crapă nimic, dar apare un tile unde dashboard-ul devine brusc lent/nereactiv cât timp rulează acel tile. Genul de bug care se descoperă abia când adaugi ceva nou.
Debugging mai greu, nu performanță mai slabă — cu 229 de variabile globale și tot codul într-un singur fișier, orice bug subtil de state (ex: un tile care nu-și resetează corect un flag) e mai greu de urmărit. Nu afectează viteza de rulare, dar te costă timp când apare ceva ciudat.

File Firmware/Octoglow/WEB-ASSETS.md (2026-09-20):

# `build_web.py` — cum ajunge interfața web în firmware

Documentație pentru oricine modifică interfața sau vrea să contribuie.

---

## Regula scurtă

**După orice modificare în `portal.html` sau `auth.html`, rulează:**

```bash
python build_web.py
```

**abia apoi compilezi.** Dacă uiți, nu primești nicio eroare — sketch-ul compilează
liniștit și flash-ezi versiunea veche a interfeței. Ăsta e singurul mod în care
lanțul te poate mușca, și e tăcut.

Obicei recomandat: rulează-l pur și simplu de fiecare dată înainte de compilare,
fără să te întrebi dacă ai schimbat ceva. Dacă nimic nu s-a modificat, îți spune
„era deja la zi, nimic de făcut", nu rescrie fișierul și nu declanșează o
recompilare inutilă. Costă o secundă.

---

## De ce există

Interfața web era înainte un raw string în `Octoglow.ino`:

```cpp
const char PORTAL_HTML[] PROGMEM = R"PORTALHTML( ... 400 KB de HTML ... )PORTALHTML";
```

Cu 404 KB de text brut, pagina ocupa **~23% din tot binarul** și ducea sketch-ul
la 87% din partiția de aplicație. Nu mai era loc de crescut.

Soluția: pagina se comprimă gzip la build și se trimite comprimată, cu antetul
`Content-Encoding: gzip`. Browserul o decomprimă singur, deci utilizatorul
primește exact aceiași octeți ca înainte — dar în flash ocupă 85 KB în loc de 404.

| | înainte | după |
|---|---|---|
| `portal.html` | 404.111 | 84.694 (21,0%) |
| `auth.html` | 13.681 | 4.161 (30,4%) |
| **sketch total** | **1.718.319 (87%)** | **1.389.551 (70%)** |

RAM-ul nu se schimbă: tablourile sunt `PROGMEM`, deci stau în flash, nu în RAM.

---

## Cum funcționează lanțul

```
portal.html  ─┐
              ├─►  build_web.py  ─►  web_assets.h  ─►  #include în Octoglow.ino
auth.html    ─┘      (gzip -9)        (generat)              │
                                                              ▼
                                                      sendGzipHtml()
                                                   Content-Encoding: gzip
                                                              │
                                                              ▼
                                                   browserul decomprimă
```

### Fișierele

| Fișier | Rol | În git? |
|---|---|---|
| `portal.html` | dashboard-ul, **sursa de adevăr** — aici editezi | da |
| `auth.html` | pagina de login | da |
| `build_web.py` | generatorul | da |
| `web_assets.h` | **generat** — nu edita manual | vezi mai jos |

`web_assets.h` este regenerabil integral: șterge-l și `build_web.py` îl reface
identic bit cu bit. Poate sta în `.gitignore` (istoric curat, diff-uri lizibile în
`portal.html`) cu prețul că oricine clonează repo-ul trebuie să ruleze scriptul
înainte de prima compilare — altfel `#include "web_assets.h"` eșuează cu
*No such file or directory*.

---

## Ce conține `web_assets.h`

Nu conține logică, doar date:

```cpp
// portal.html: 404111 -> 84694 bytes
#define PORTAL_HTML_GZ_SRC_SHA "93dac1ca6e9f1a32"
const uint8_t PORTAL_HTML_GZ[] PROGMEM = {
  0x1f, 0x8b, 0x08, 0x00, ...
};
const uint32_t PORTAL_HTML_GZ_LEN = 84694;
```

Pentru fiecare fișier sursă se generează trei simboluri:

- `<SIMBOL>[]` — octeții comprimați. Primii trei (`1f 8b 08`) sunt semnătura gzip.
- `<SIMBOL>_LEN` — lungimea, ca firmware-ul să știe cât să trimită.
- `<SIMBOL>_SRC_SHA` — primii 16 hex din SHA-256 al **sursei necomprimate**.
  Nu e folosit de firmware; e o urmă care spune ce HTML a produs blobul, utilă
  când te uiți la un diff sau la un binar și vrei să știi din ce provine.

---

## Cum îl folosește firmware-ul

Trei locuri în `Octoglow.ino`:

```cpp
#include "web_assets.h"                       // linia ~5531

static void sendGzipHtml(const uint8_t* body, uint32_t len) {
  server.sendHeader("Content-Encoding", "gzip");
  server.setContentLength(len);
  server.send(200, "text/html", "");
  server.sendContent_P((PGM_P)body, len);
}
```

apoi, în `handleDashboard()` și `handleRoot()`:

```cpp
sendGzipHtml(PORTAL_HTML_GZ, PORTAL_HTML_GZ_LEN);
sendGzipHtml(AUTH_SHELL_GZ,  AUTH_SHELL_GZ_LEN);
```

`sendHeader()` trebuie apelat **înainte** de `send()` — `WebServer` adună
antetele și le emite la `send()`.

---

## Detalii de implementare

### `mtime=0` la compresie

```python
blob = gzip.compress(raw, compresslevel=9, mtime=0)
```

Implicit, gzip scrie timestamp-ul curent în header, deci **același HTML ar produce
octeți diferiți la fiecare rulare**. Asta ar rescrie `web_assets.h` de fiecare
dată, ar murdări fiecare diff din git și ar forța Arduino să recompileze un fișier
de 5.574 de linii degeaba. Cu `mtime=0` generarea e deterministă.

### Scrierea e idempotentă

Scriptul construiește conținutul complet în memorie și îl compară cu ce e pe disc.
Dacă e identic, **nu atinge fișierul** — deci mtime-ul rămâne neschimbat și Arduino
nu vede niciun motiv de recompilare.

### Nu minifică

Scriptul doar comprimă. Nu atinge HTML-ul, nu redenumește variabile, nu scoate
spații. De asta se poate demonstra echivalența bit cu bit (vezi mai jos). Gzip
elimină oricum redundanța pe care ar fi vizat-o o minificare; măsurat pe acest
proiect, scoaterea indentării ar fi adus doar 57 KB, față de 319 KB de la gzip.

---

## Utilizare

```bash
python build_web.py           # regenerează web_assets.h
python build_web.py --check   # doar verifică; ies cu cod 1 dacă nu e la zi
```

`--check` nu scrie nimic. E gândit pentru un git hook sau CI, ca să nu se poată
comita un `web_assets.h` rămas în urmă față de `portal.html`. Exemplu de
`.git/hooks/pre-commit`:

```bash
#!/bin/sh
cd Firmware/Octoglow && python build_web.py --check || {
  echo "Ruleaza: python build_web.py"
  exit 1
}
```

Cerințe: Python 3 (testat pe 3.14), doar biblioteca standard — `gzip`, `hashlib`,
`os`, `sys`. Fără dependențe externe.

---

## Cum adaugi o pagină nouă

1. Pui fișierul `.html` lângă sketch.
2. Îl adaugi în lista din `build_web.py`:

```python
ASSETS = [
    ("portal.html", "PORTAL_HTML_GZ"),
    ("auth.html",   "AUTH_SHELL_GZ"),
    ("pagina.html", "PAGINA_GZ"),        # nou
]
```

3. Rulezi scriptul și îl servești cu `sendGzipHtml(PAGINA_GZ, PAGINA_GZ_LEN)`.

Nu trebuie modificat nimic altceva — restul generatorului e generic.

---

## Capcane de reținut

**Paginile nu mai pot conține substituții la runtime.** Înainte ar fi fost posibil
să cauți și să înlocuiești ceva în string înainte de trimitere; într-un blob gzip
nu se poate. Momentan nu se face nicio substituție — ambele pagini se trimit
verbatim, toate datele vin prin `/state` și celelalte endpointuri JSON — deci
restricția nu costă nimic. Dacă vreodată ai nevoie de conținut dinamic în HTML,
îl adaugi ca endpoint JSON, nu ca substituție în pagină.

**Clienții trebuie să accepte gzip.** Nu există fallback necomprimat — versiunea
brută nu mai există în flash. Toate browserele trimit `Accept-Encoding: gzip`, iar
singurul alt consumator din proiect, Octoglow Connect, vorbește doar cu
endpointurile JSON (`/nowplaying`, `/notification`, `/ets2speed`), nu cu paginile.
Dacă testezi cu `curl`, folosește `curl --compressed`, altfel primești octeți gzip
în terminal.

**`portal.html` e UTF-8 fără BOM și are diacritice.** Scriptul citește binar
(`open(..., "rb")`), deci encoding-ul e păstrat exact. Ai grijă ca editorul tău să
nu adauge BOM și să nu convertească terminatorii de linie — ar schimba octeții
trimiși.

**Nu edita `web_assets.h`.** Orice modificare se pierde la următoarea rulare a
scriptului.

---

## Verificare

Că lanțul e corect se poate demonstra, nu doar presupune:

```bash
# 1. gzip-ul se decomprimă înapoi în sursă, bit cu bit
python -c "
import gzip
h = open('web_assets.h', encoding='utf-8').read()
i = h.index('PORTAL_HTML_GZ[] PROGMEM = {'); j = h.index('};', i)
b = bytes(int(t,16) for t in h[h.index('{',i)+1:j].replace('\n',' ').split(',') if t.strip())
print(gzip.decompress(b) == open('portal.html','rb').read())
"

# 2. generarea e deterministă
python build_web.py && python build_web.py --check
```

Ambele au fost rulate la introducerea acestui lanț: round-trip identic pe toți cei
404.111 octeți, iar ștergerea și regenerarea lui `web_assets.h` a produs un fișier
identic bit cu bit.

---

## Depanare

| Simptom | Cauză | Rezolvare |
|---|---|---|
| `web_assets.h: No such file or directory` la compilare | headerul lipsește (proaspăt clonat, sau ignorat de git) | `python build_web.py` |
| Modificările din interfață nu apar după flash | ai uitat să rulezi scriptul | `python build_web.py`, apoi recompilează |
| Browserul descarcă un fișier în loc să afișeze pagina | `Content-Encoding` lipsă sau greșit la trimitere | verifică `sendGzipHtml()` |
| `curl` scoate caractere ilizibile | curl nu cere gzip implicit | `curl --compressed` |
| Diff uriaș în `web_assets.h` la o schimbare minusculă | normal — gzip-ul se schimbă global la orice modificare | citește diff-ul din `portal.html`, nu din header |

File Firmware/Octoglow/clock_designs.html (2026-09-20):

Octoglow · MAX7219 · 4 module FC16

# Fețe de ceas pentru matricea 8×32

Douăsprezece variante compacte: oră + ziua săptămânii și oră + dată. Fiecare cadru e desenat din 32 de coloane de câte 8 biți, exact cum le trimite firmware-ul cu mx.setColumn(31 − col, val), cu fonturile din Octoglow.ino (TIKO 3×7, Mako 4×7 și 5×7) plus două fonturi mici noi, cu codul C la final.

Limbă

ROEN

Format

24h12h

Timp

AcumDemo rapid

„:” clipește Zero în față

LED

Afișat

## Oră + ziua săptămânii

Toate încap fără derulare. Insigna verde e verificată automat pe toate combinațiile: RO/EN, 24h/12h, cu și fără zero în față, fiecare zi a săptămânii. Bara și cursorul încep cu luni.

## Oră + dată

Ora și data completă nu încap lizibil una lângă alta: chiar și cu cifre de 3×5, „12:45 11.09” are nevoie de 36 de coloane. De aceea variantele de mai jos arată doar ziua lunii sau alternează.

## Fonturi noi

TIKO 3×7, Mako 4×7 și 5×7 există deja în Octoglow.ino. Variantele compacte mai au nevoie de două fonturi mici, în același format: un octet pe coloană, bitul 0 = rândul de sus.

Fișier de referință: build_web.py împachetează doar portal.html și auth.html, deci pagina asta nu ajunge în firmware.

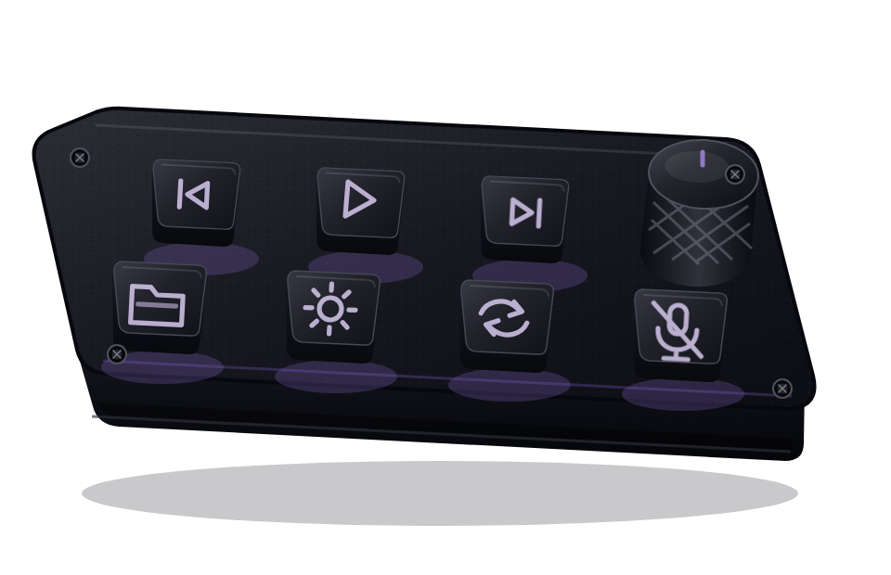
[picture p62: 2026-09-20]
Octoglow Connect/Beta/Octoglow Connect/Assets/octoglow_macro_preview.png

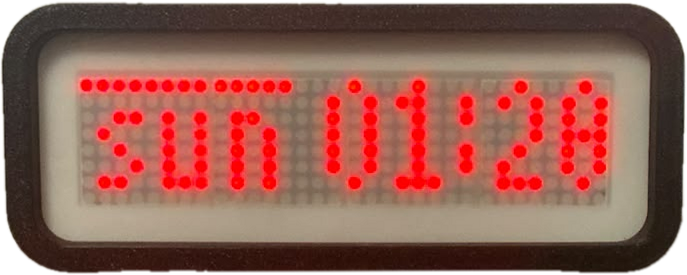
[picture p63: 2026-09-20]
Octoglow Connect/Beta/Octoglow Connect/Assets/smartclock-nobg_2.png

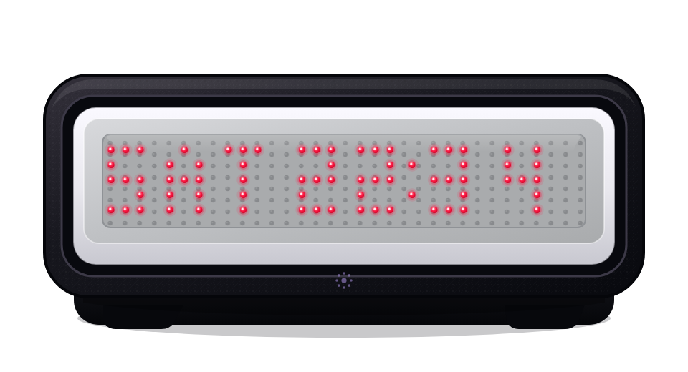
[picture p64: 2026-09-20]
Octoglow Connect/Beta/Octoglow Connect/Assets/octoglow_clock_preview.png

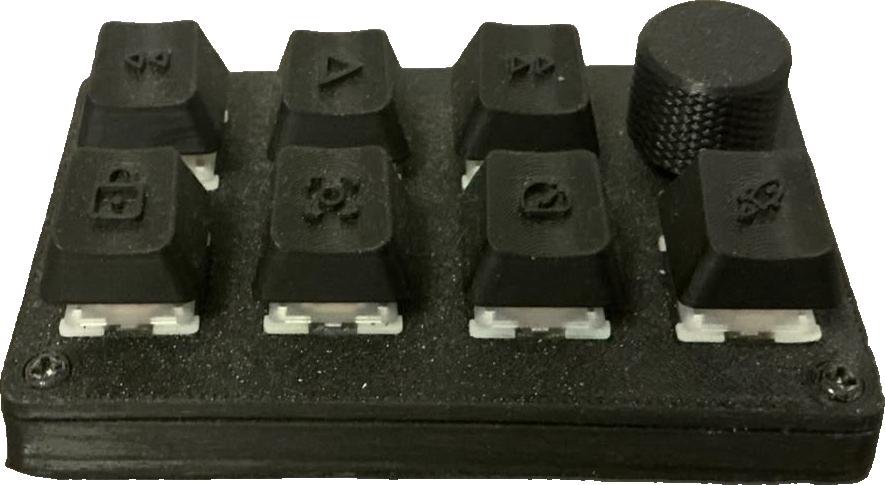
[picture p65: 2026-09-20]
Octoglow Connect/Beta/Octoglow Connect/Assets/macropad-nobg.png

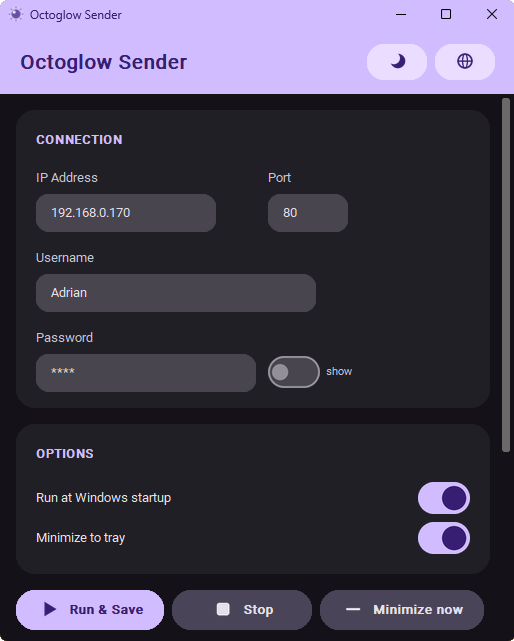
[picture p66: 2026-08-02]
Web/Octoglow_Sender.png

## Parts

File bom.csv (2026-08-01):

Item | Description | Qty | Unit Price ($) | Total ($) | URL | Running Total ($)
LED Matrix 4x MAX7219 | 4-in-1 chained MAX7219 red LED matrix module | 1 | $6,98 | $6,98 | https://sigmanortec.ro/en/led-matrix-module-4x-max7219-red | $6,98
ESP32-C3 SuperMini | WiFi/BT microcontroller board 3.3V | 1 | $6,09 | $6,09 | https://sigmanortec.ro/en/esp32-c3-supermini-development-board-33v-wifi-bluetooth | $13,07
TTP223 Touch Sensor | Capacitive touch button module | 1 | $0,69 | $0,69 | https://sigmanortec.ro/en/capacitive-button-ttp223-touch | $13,76
TP4056 + Boost 5-24V | Battery charger with boost converter 5-24V | 1 | $1,75 | $1,75 | https://sigmanortec.ro/modul-incarcare-baterie-cu-ridicator-5-24v-tp4056 | $15,51
IP2312 Charger USB-C 3A | Li-Ion charger 5V→4.2V CC/CV Type-C 3A QC | 1 | $2,75 | $2,75 | https://sigmanortec.ro/modul-incarcare-litiu-5v-la-42v-ip2312-cv-cc-type-c-3a-qc | $18,26
Mini Switch | Small slide switch, 2 positions | 1 | $0,22 | $0,22 | https://sigmanortec.ro/en/mini-switch-2-positions | $18,48
18650 2500mAh x2 | Samsung 25R 18650 3.7V 2500mAh - set of 2 | 1 | $15,55 | $15,55 | https://sigmanortec.ro/set-2-acumulator-li-ion-25r-18650-37v-2500mah-8c | $34,03
BMP280 Sensor 5V | Pressure and temperature sensor 5V | 1 | $2,03 | $2,03 | https://sigmanortec.ro/en/pressure-and-temperature-sensor-bmp280-5v | $36,06
3D Printing | Custom 3D printed case (Printing Legion) | 1 | $12,00 | $12,00 | - | $48,06
TOTAL |  |  |  | $48,06 |  | $48,06

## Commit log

2026-08-01 Released Octoglow Sender and Octoglow Watch
    [Schematics.fzz, bom.csv]
2026-08-02 Final update for readme for now
    [Schematics.fzz]
2026-08-21 /State fixes + Icon settings + C# Octoglow conect
    [Schematics.fzz]
